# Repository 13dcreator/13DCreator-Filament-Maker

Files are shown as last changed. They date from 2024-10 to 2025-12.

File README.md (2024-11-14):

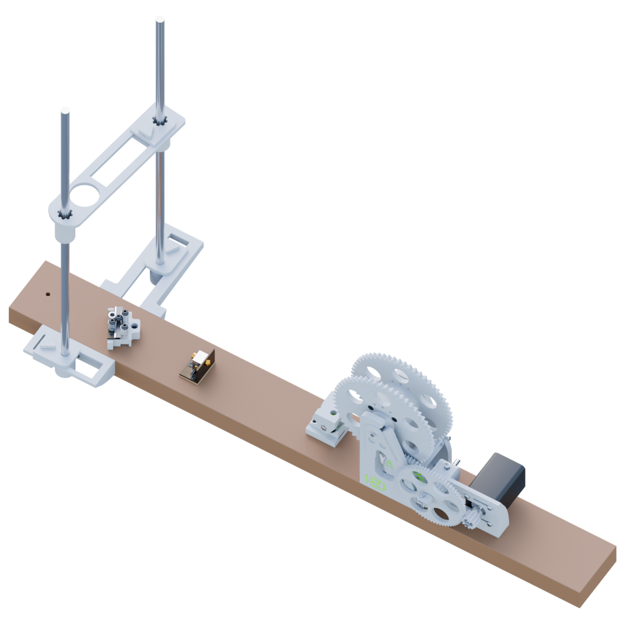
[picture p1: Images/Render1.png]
Render1


[English](#english)

## Bahasa Indonesia

PET Filament Maker adalah perangkat yang dirancang untuk mengubah botol PET bekas menjadi filament 3D yang dapat digunakan kembali. Proyek ini bertujuan memberikan solusi yang ramah lingkungan, mengurangi limbah plastik sekaligus menghemat biaya material filament yang biasanya harus dibeli.

Rekomendasi Penggunaan Extruder:
Disarankan untuk menggunakan Dual Gear Extruder agar cengkeraman terhadap filament lebih kuat dan stabil, karena diameter filament mungkin tidak selalu konsisten.

Proses Kerja:
1. Persiapan Bahan: Botol PET bekas dibersihkan terlebih dahulu untuk menghilangkan label dan kotoran agar siap diproses.
2. Pelurusan Permukaan Botol: Botol PET yang memiliki permukaan tidak rata perlu diluruskan dengan memanaskan permukaannya sambil memutar botol menggunakan blower, heatgun atau di atas kompor. Proses pemanasan ini mengurangi lekukan, memungkinkan permukaan botol menjadi lebih rata dan mudah dipotong.
3. Ekstrusi: Botol PET dipotong menjadi strip dan dipanaskan hingga lunak untuk diubah menjadi bentuk filament, kemudian ditarik secara otomatis agar ukuran filament konsisten.
4. Pemeriksaan Kualitas Filament: Filament yang dihasilkan diperiksa untuk memastikan kualitas dan ketebalan sesuai spesifikasi.

Kelemahan:
1. Hasil filament yang dihasilkan tidak selalu konsisten, sangat tergantung dengan konsistensi potongan.
2. Dapat mengakibatkan macet jika diameter filament terlalu kecil atau terlalu besar.
3. Putaran stepper motor sering terhambat saat ESP8266 terhubung ke WiFi. Pastikan untuk memutus koneksi WiFi pada ESP8266 saat proses pembuatan filament.
4. Suara stepper motor cukup berisik; coba atur microstepping untuk menguranginya.
5. Suara cutter cukup keras saat memotong botol, terutama untuk botol PET yang tebal; bisa disiasati dengan menggunakan pelumas.
6. Deteksi filament terkadang terhenti jika filament yang ditarik oleh filament puller kendur atau terlalu tipis.

Kesimpulan:

Filament Maker dari botol PET bekas ini memberikan solusi ekonomis sekaligus ramah lingkungan, memungkinkan pengguna mendaur ulang plastik bekas menjadi filament yang siap digunakan dalam pencetakan 3D. Dengan desain yang mudah dioperasikan, kontrol otomatis yang presisi, dan sistem modular yang mempermudah perawatan, proyek ini menawarkan pendekatan baru yang berkelanjutan dalam produksi material 3D.

## English

PET Filament Maker is a tool designed to convert used PET bottles into reusable 3D filament. This project aims to provide an eco-friendly solution by reducing plastic waste while saving on filament material costs, which are typically purchased.

Extruder Usage Recommendation: It is recommended to use a Dual Gear Extruder for stronger and more stable grip on the filament, as the filament diameter may not always be consistent.

How It Works:

1. Material Preparation: The used PET bottles are cleaned first to remove labels and dirt, making them ready for processing.
2. Surface Straightening: PET bottles with uneven surfaces need to be straightened by heating the surface while rotating the bottle using a blower, heat gun, or stovetop. This heating process reduces the wrinkles, making the bottle surface smoother and easier to cut.
3. Extrusion: The PET bottles are cut into strips and heated until soft to be shaped into filament, then automatically drawn to ensure the filament size remains consistent.
4. Filament Quality Check: The produced filament is checked to ensure that its quality and thickness meet the specifications.

Disadvantages:

1. The filament produced is not always consistent and highly depends on the consistency of the cuts.
2. It may cause clogging if the filament diameter is too small or too large.
3. The stepper motor's rotation is often hindered when the ESP8266 is connected to WiFi. Be sure to disconnect the WiFi on the ESP8266 during the filament-making process.
4. The stepper motor can be quite noisy; try adjusting the microstepping to reduce the noise.
5. The cutter can be loud when cutting bottles, especially for thick PET bottles; this can be mitigated by using lubricants.
6. Filament detection may sometimes stop if the filament pulled by the filament puller is slack or too thin.

Conclusion:

This PET Bottle Filament Maker provides an economical and eco-friendly solution, allowing users to recycle used plastic into filament ready for 3D printing. With an easy-to-operate design, precise automatic control, and a modular system that simplifies maintenance, this project offers a sustainable approach to 3D material production.

## Download Documentation in PDF Format for Easier Viewing by:

Open the documentation file > File > Download > PDF Document (.pdf)

[Dokumentasi Bahasa Indonesia](https://docs.google.com/document/d/12gZyxp6K4KovrQUbeszD_oszRoTwFk6smVtTxPSdtus/edit?usp=sharing)

[English Documentation](https://docs.google.com/document/d/1ymJz-RaAGOkLNr1P1AoNhB6fQcQ51tFpCmrfthYmQNY/edit?usp=sharing)

[BOM/Bahan yang Diperlukan](https://docs.google.com/spreadsheets/d/1hQpWlGkNJCp8BHFFs-p2dSdpw58OgJwYKI5ZXl5ccxk/edit?usp=sharing)

## 3D Print Results

<table>
  <tr>
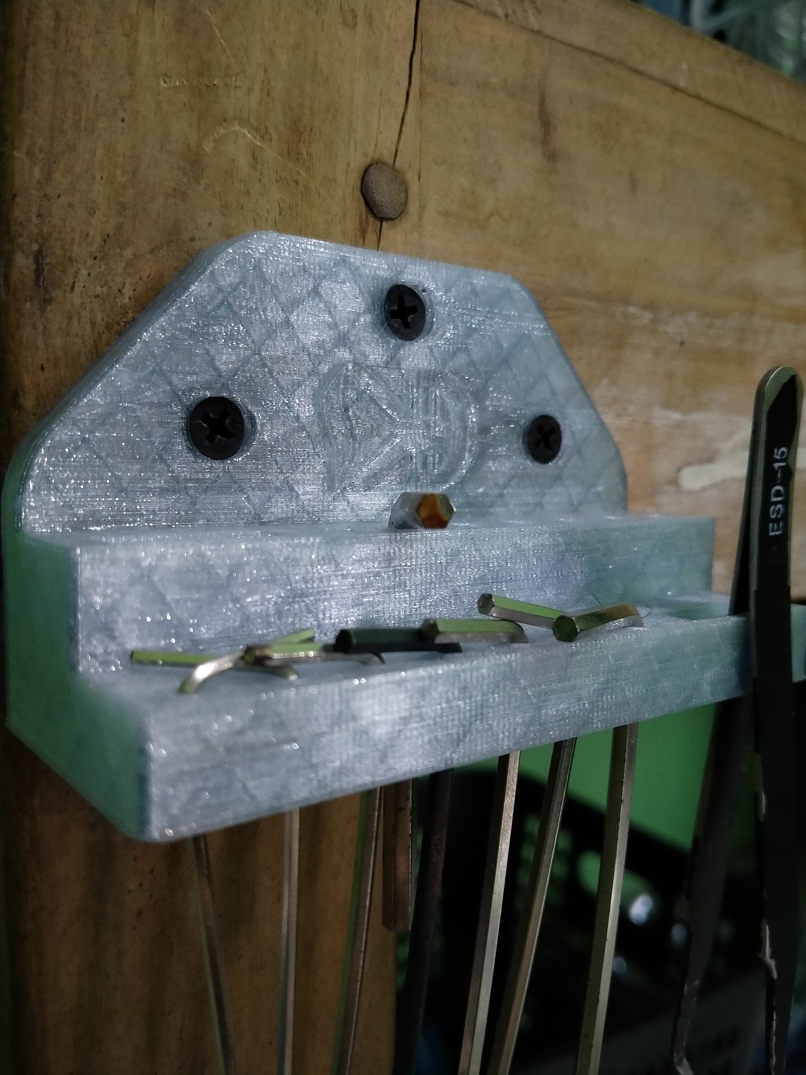
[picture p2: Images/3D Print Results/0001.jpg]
    <td></td>
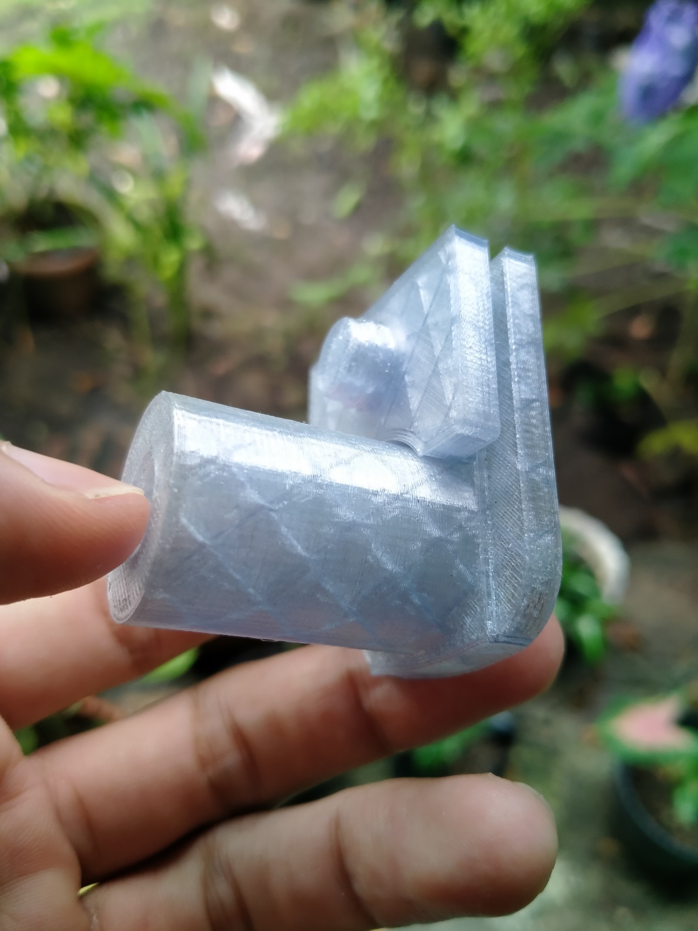
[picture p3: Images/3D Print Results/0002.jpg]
    <td></td>
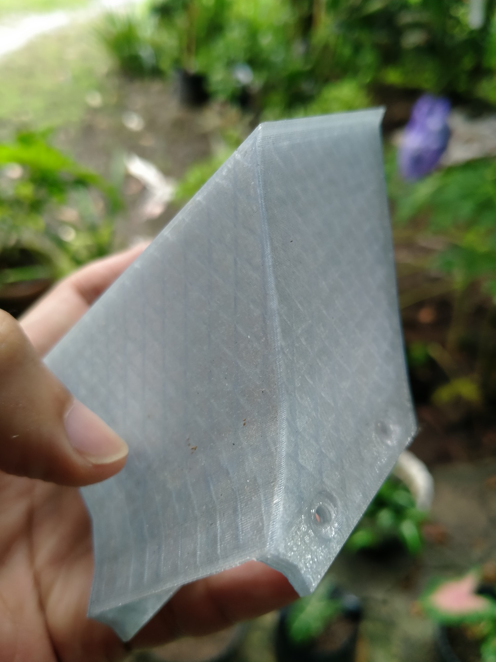
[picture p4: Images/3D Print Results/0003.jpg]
    <td></td>
  </tr>
  <tr>
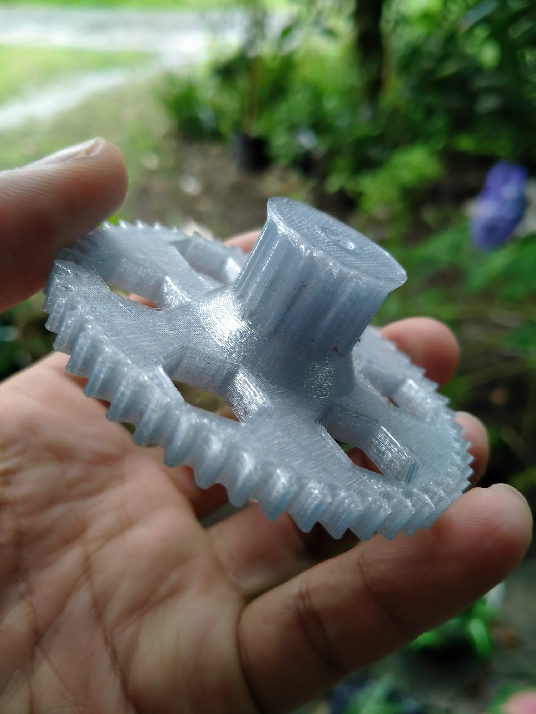
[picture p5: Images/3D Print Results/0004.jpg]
    <td></td>
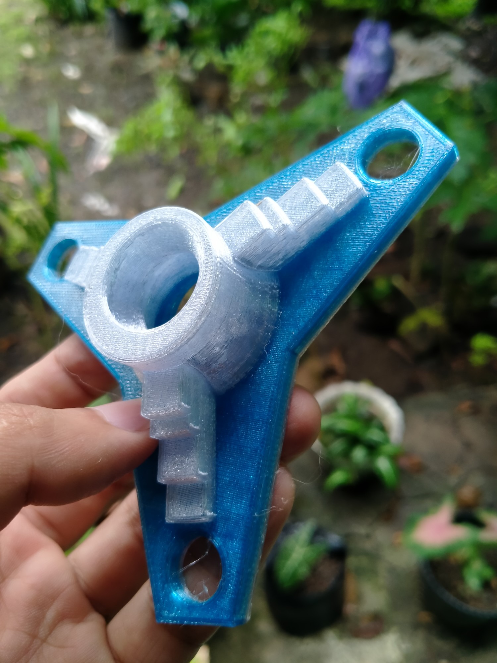
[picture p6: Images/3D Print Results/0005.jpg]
    <td></td>
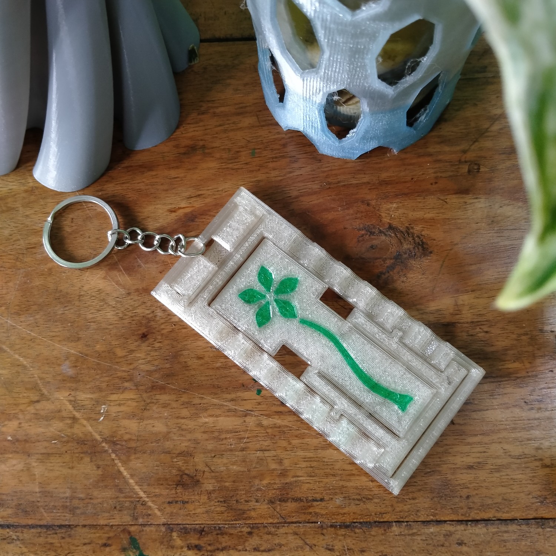
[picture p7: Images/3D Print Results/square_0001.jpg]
    <td></td>
  </tr>
  <tr>
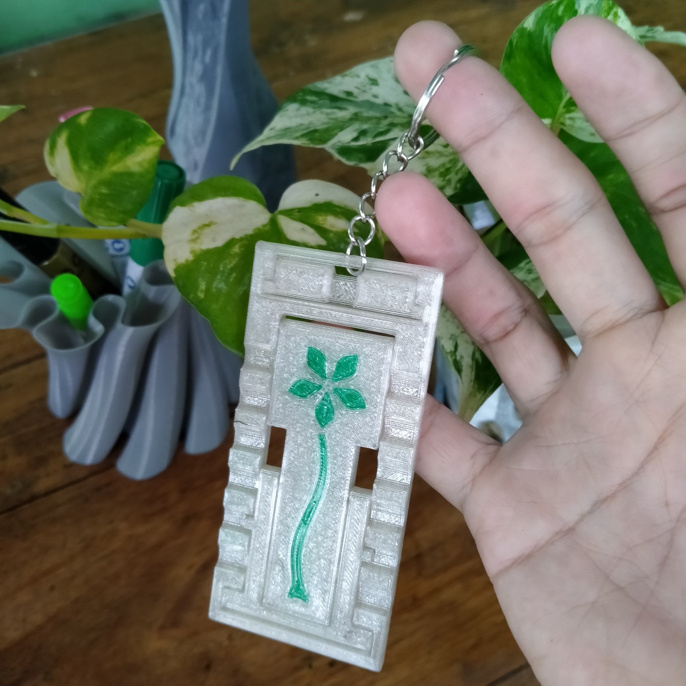
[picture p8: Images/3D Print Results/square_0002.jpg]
    <td></td>
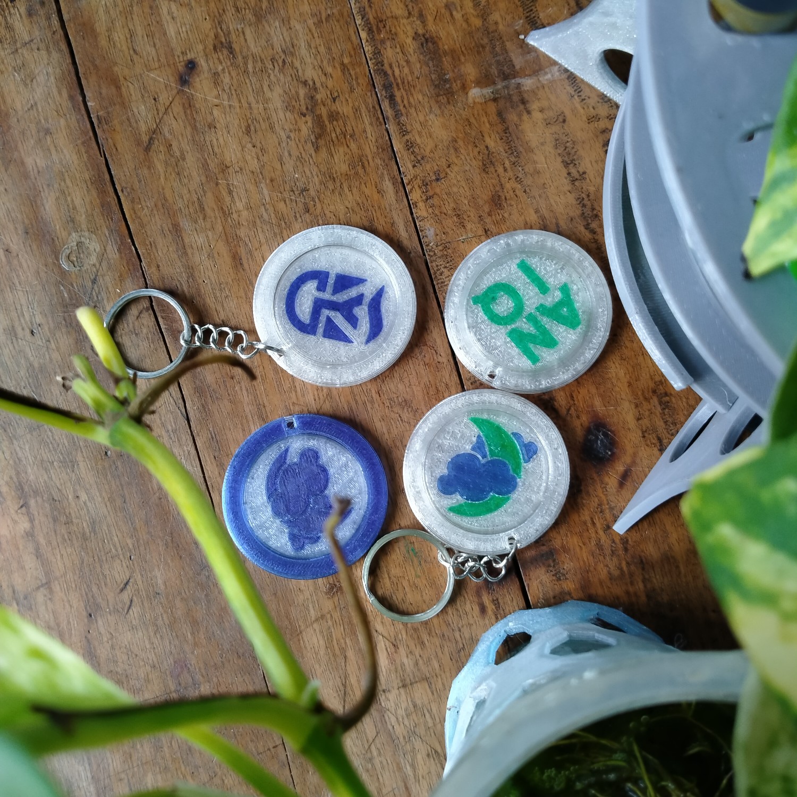
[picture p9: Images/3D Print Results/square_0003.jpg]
    <td></td>
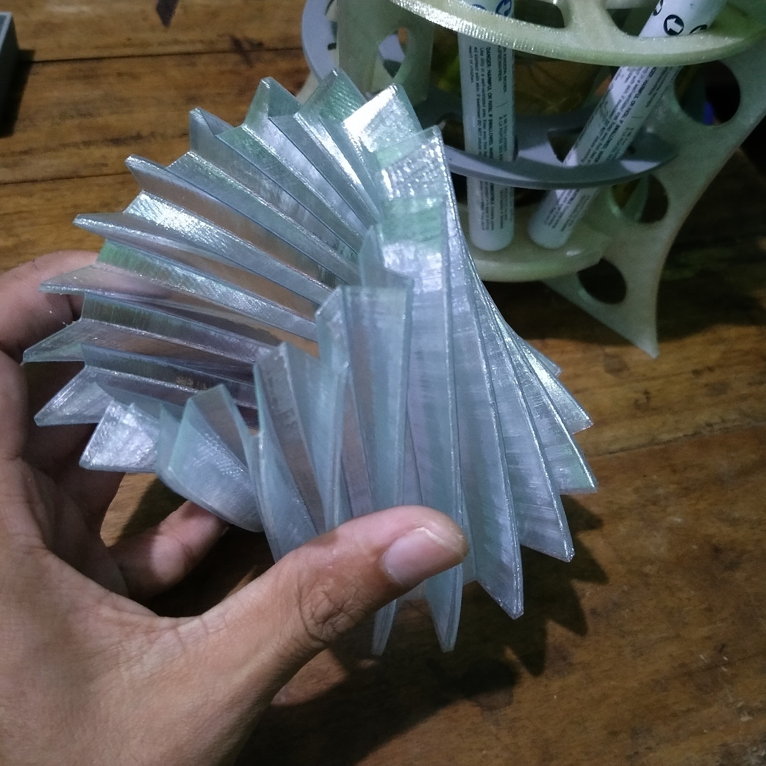
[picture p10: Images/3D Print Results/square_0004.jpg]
    <td></td>
  </tr>
</table>

## Filament Maker

<table>
  <tr>
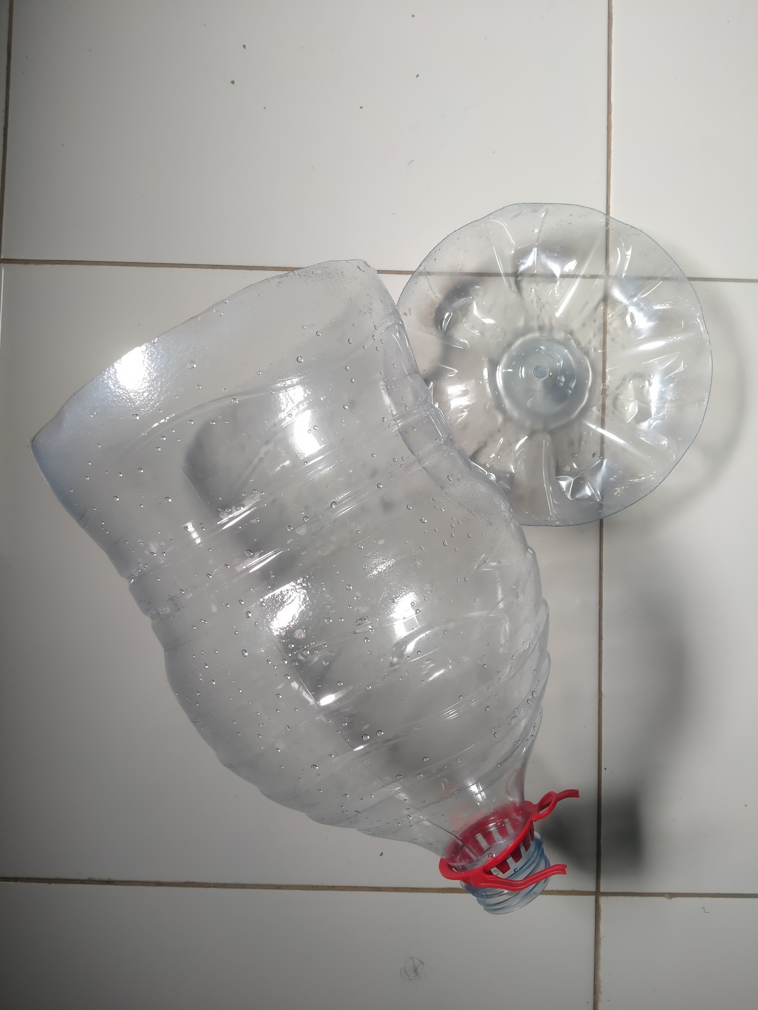
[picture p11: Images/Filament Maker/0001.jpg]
    <td></td>
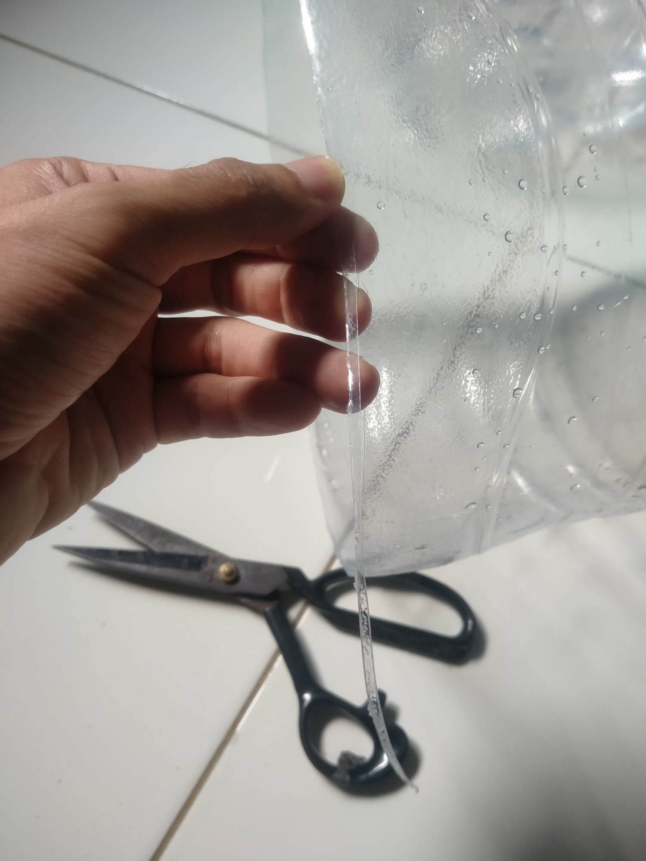
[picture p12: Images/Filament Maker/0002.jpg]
    <td></td>
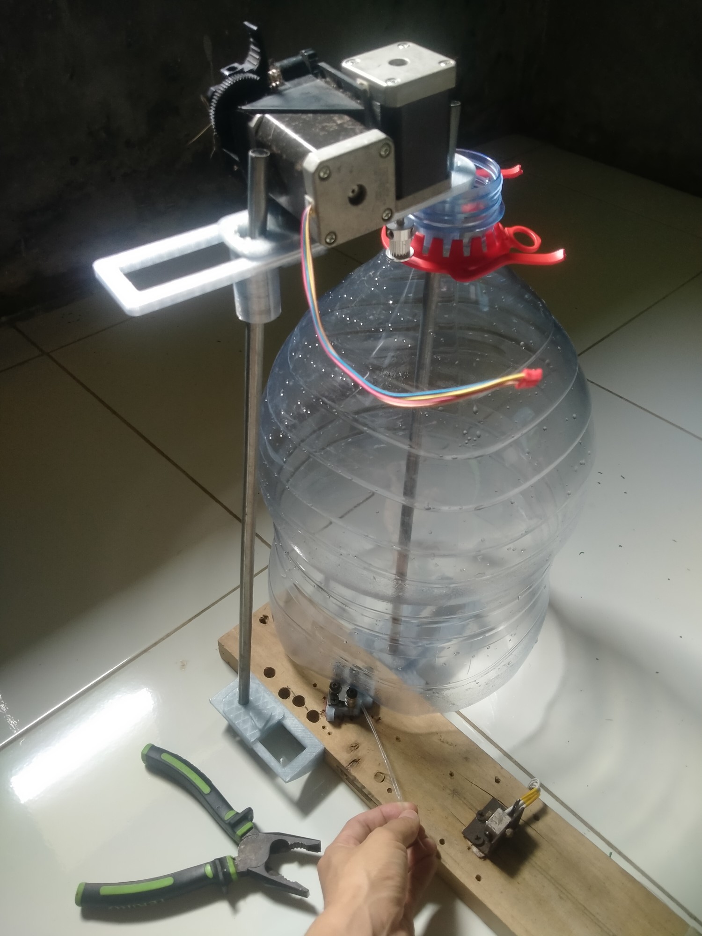
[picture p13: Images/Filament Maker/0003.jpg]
    <td></td>
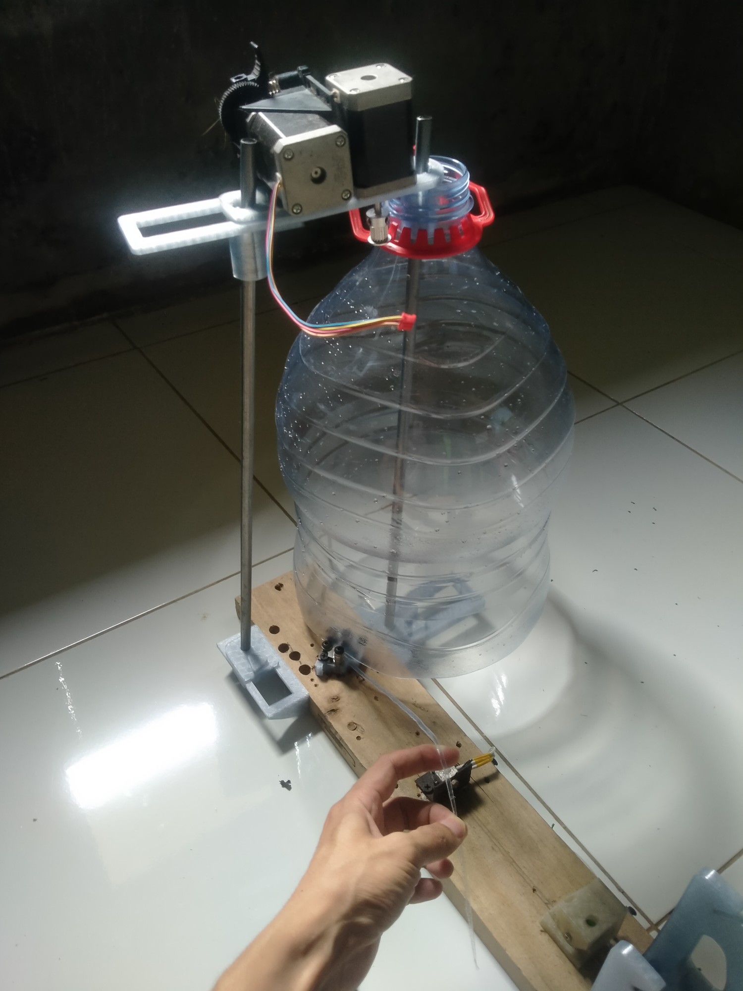
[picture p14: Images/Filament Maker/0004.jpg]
    <td></td>
  </tr>
  <tr>
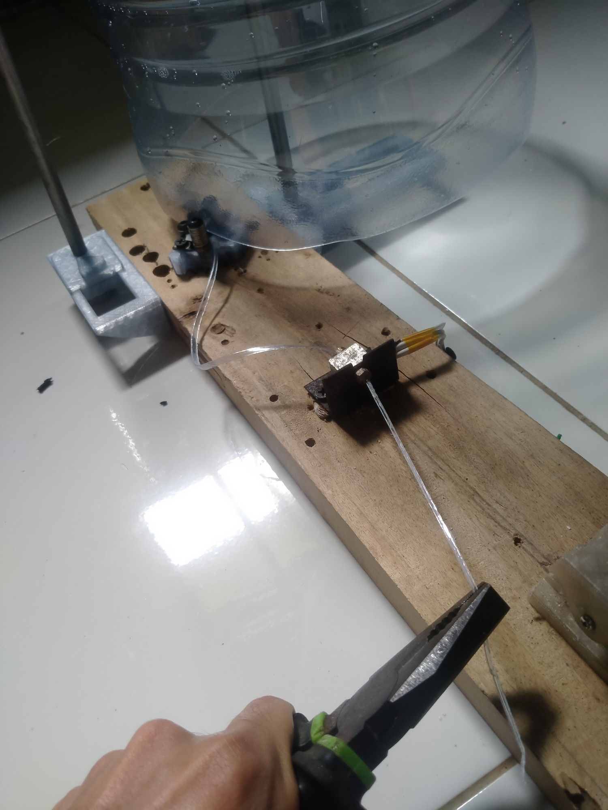
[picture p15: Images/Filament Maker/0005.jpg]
    <td></td>
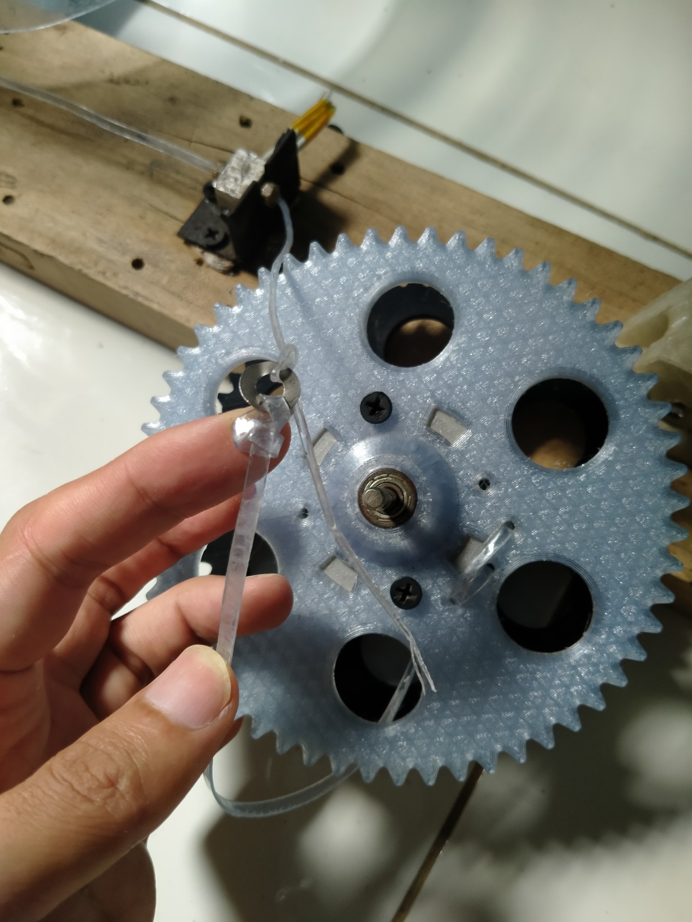
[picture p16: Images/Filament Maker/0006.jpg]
    <td></td>
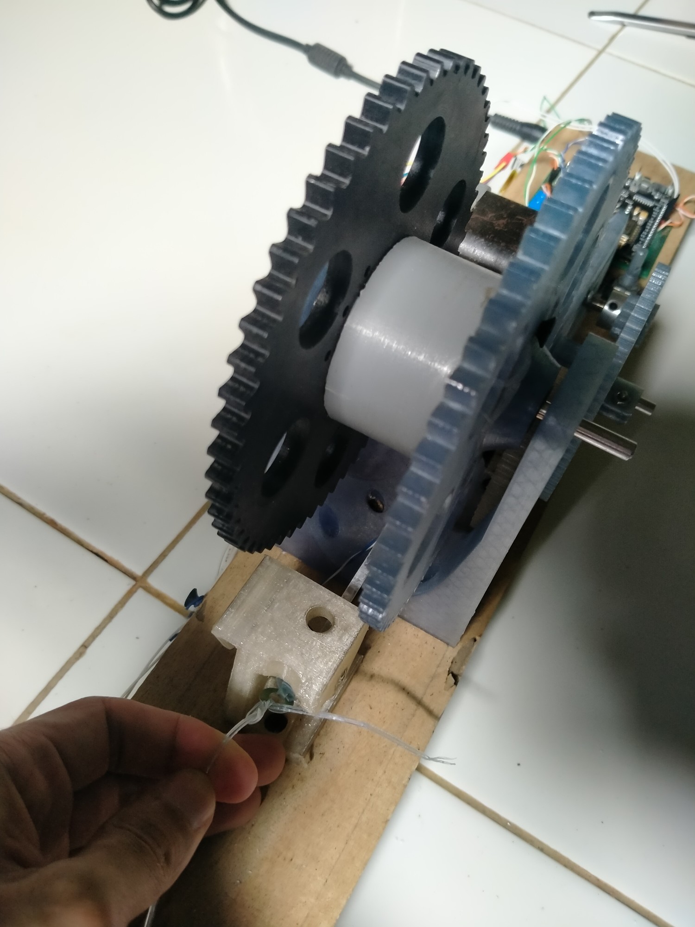
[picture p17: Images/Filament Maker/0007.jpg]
    <td></td>
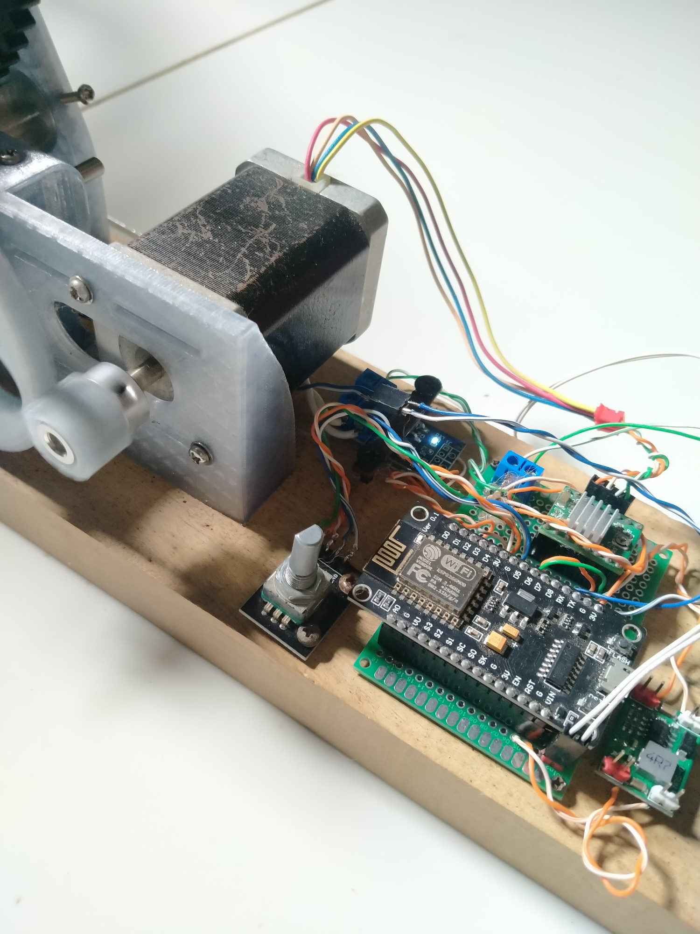
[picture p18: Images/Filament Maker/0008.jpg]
    <td></td>
  </tr>
  <tr>
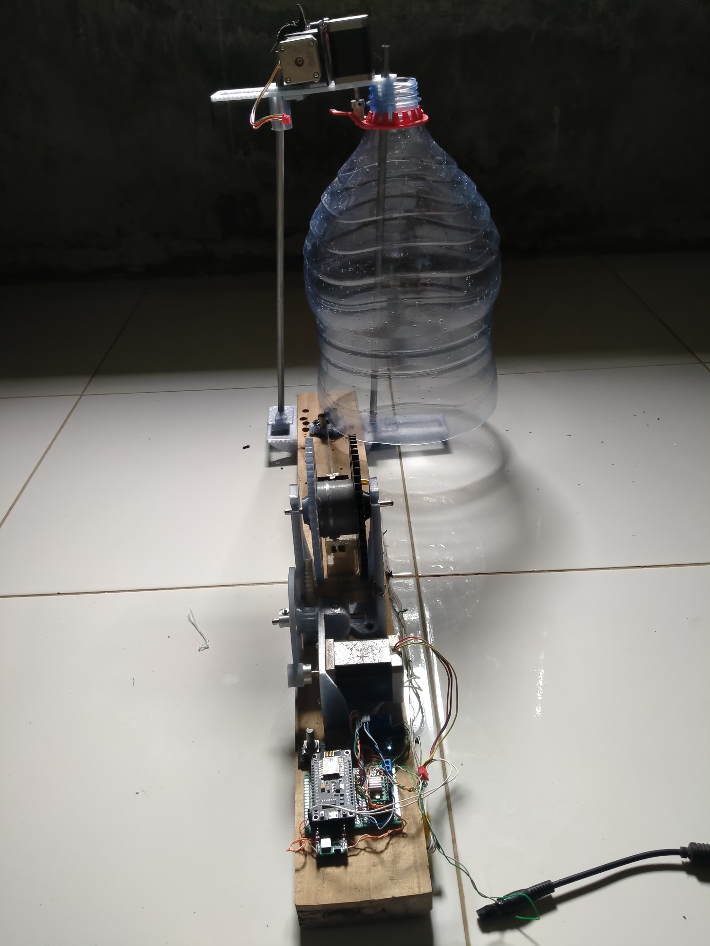
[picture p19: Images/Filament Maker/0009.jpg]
    <td></td>
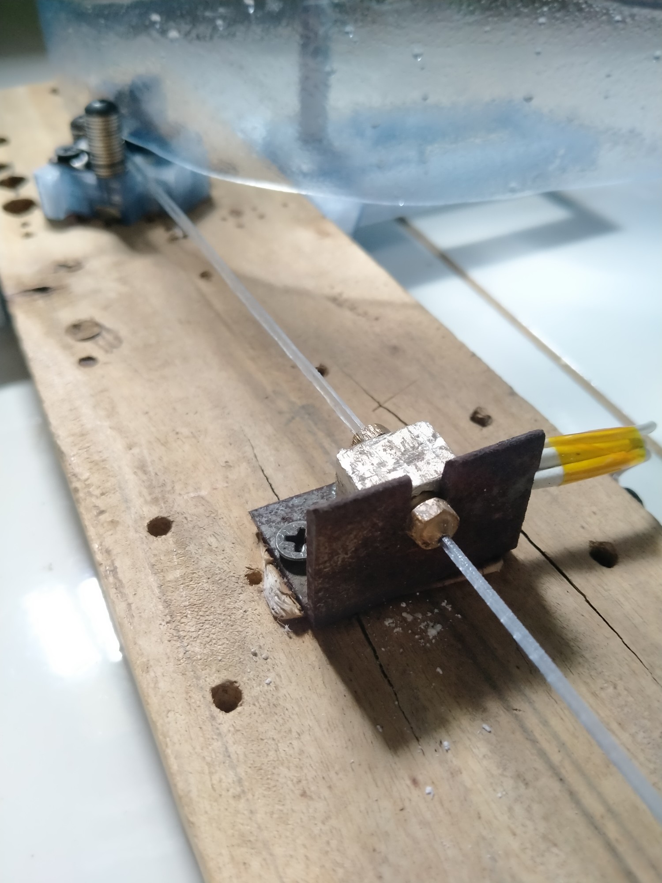
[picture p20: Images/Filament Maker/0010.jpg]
    <td></td>
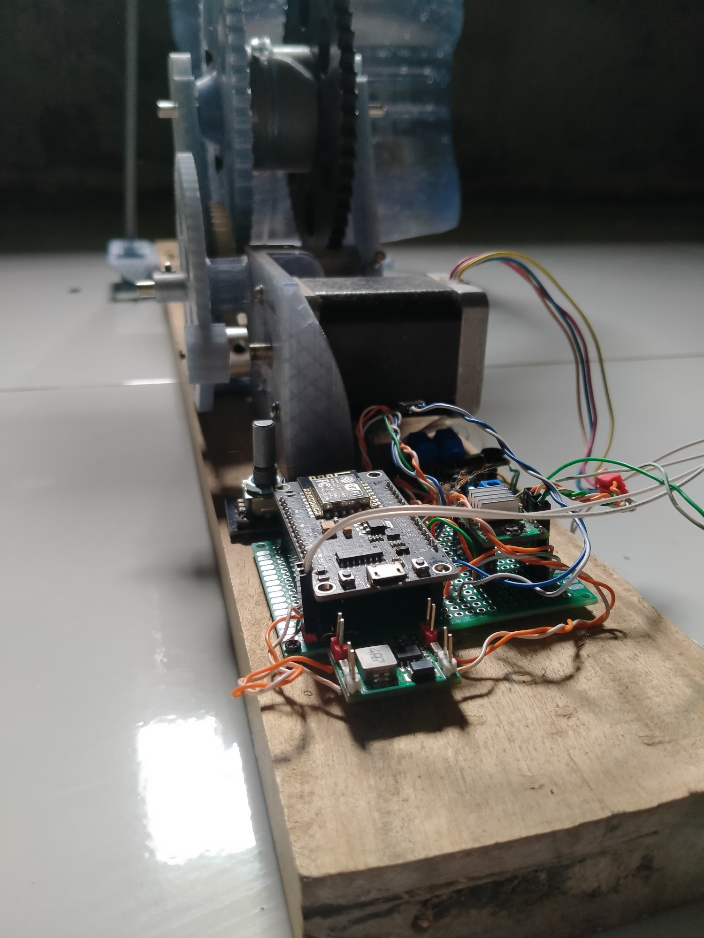
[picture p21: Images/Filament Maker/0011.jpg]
    <td></td>
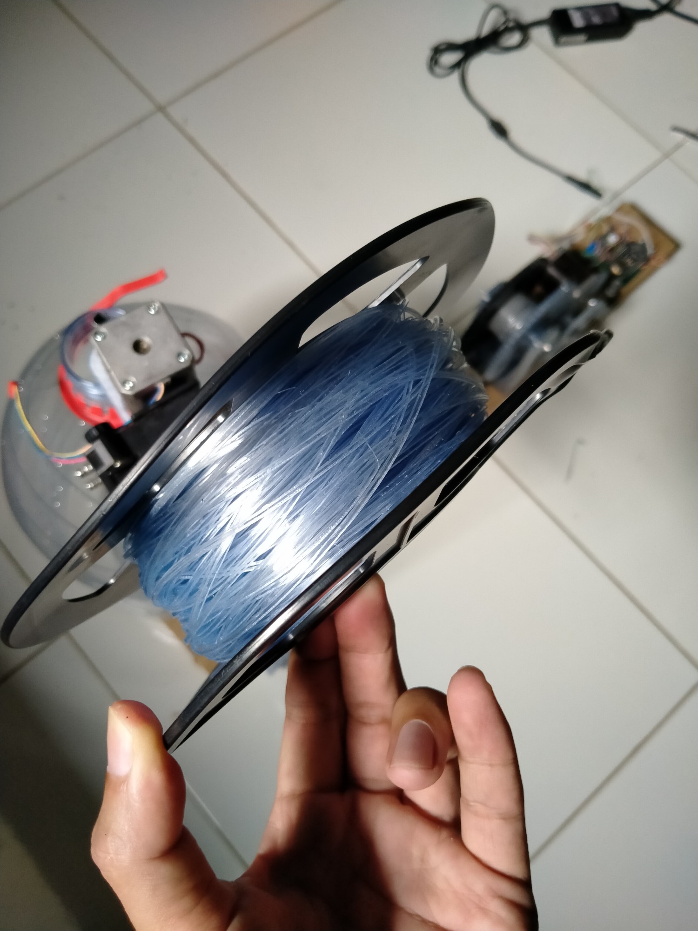
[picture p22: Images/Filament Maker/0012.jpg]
    <td></td>
  </tr>
  <tr>
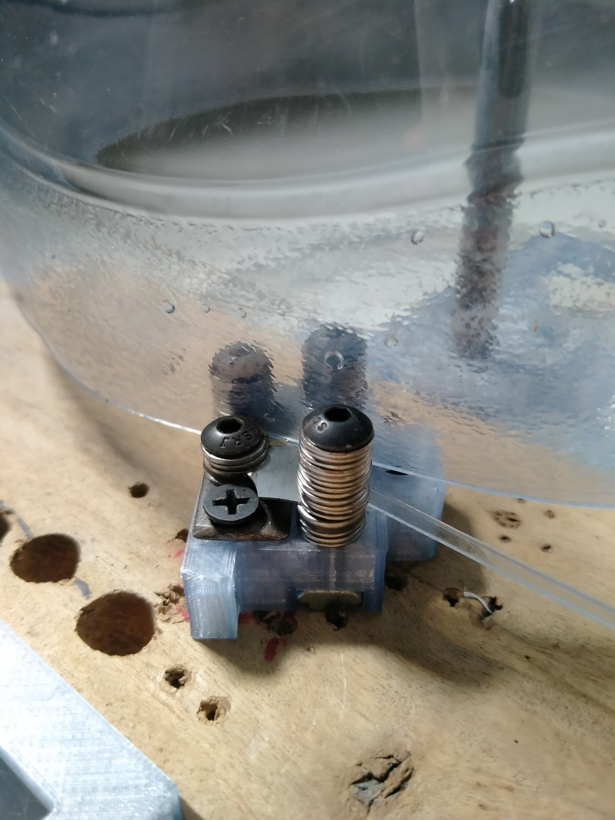
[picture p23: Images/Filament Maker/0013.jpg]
    <td></td>
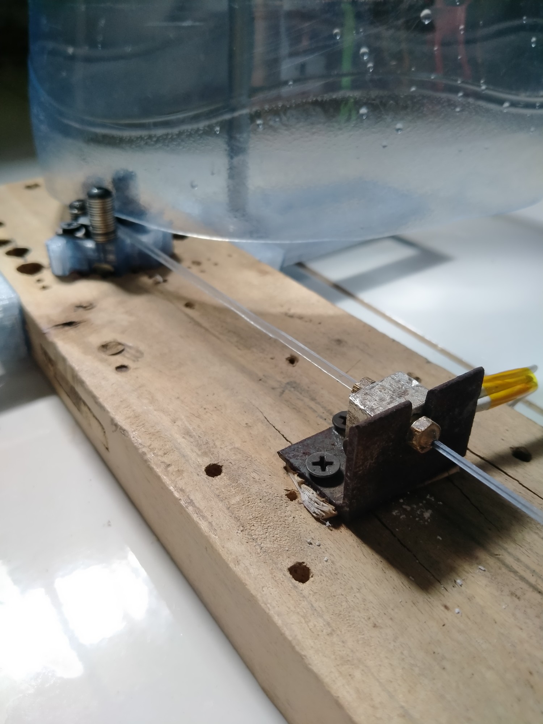
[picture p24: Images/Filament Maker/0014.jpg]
    <td></td>
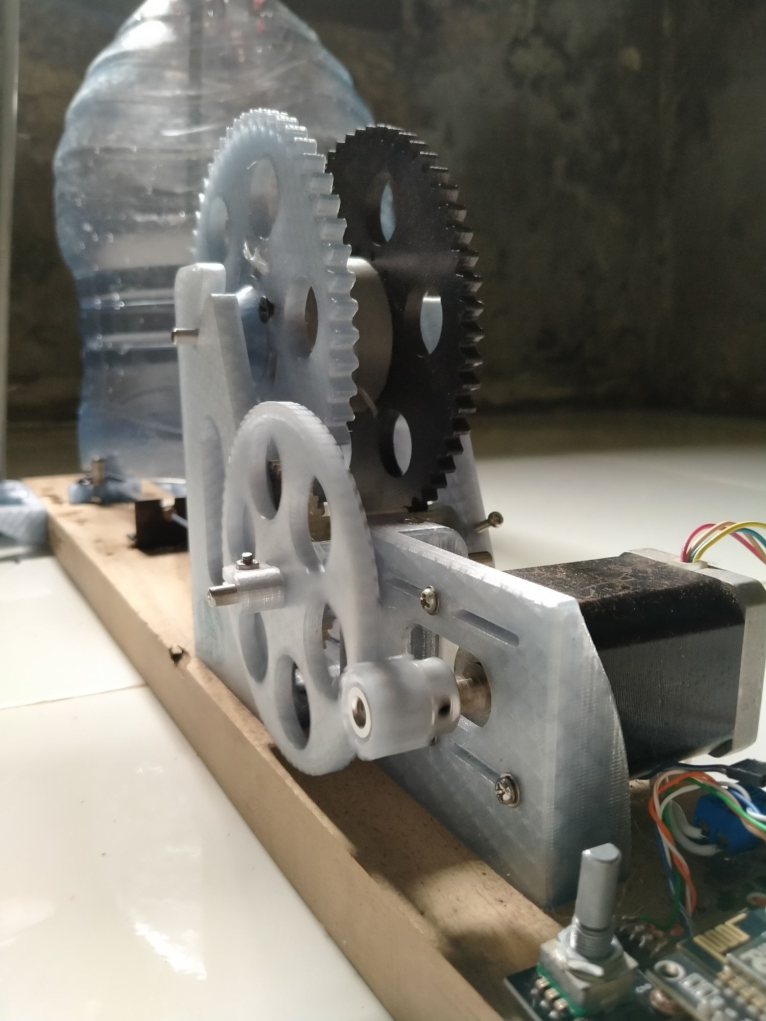
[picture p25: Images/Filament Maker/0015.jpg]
    <td></td>
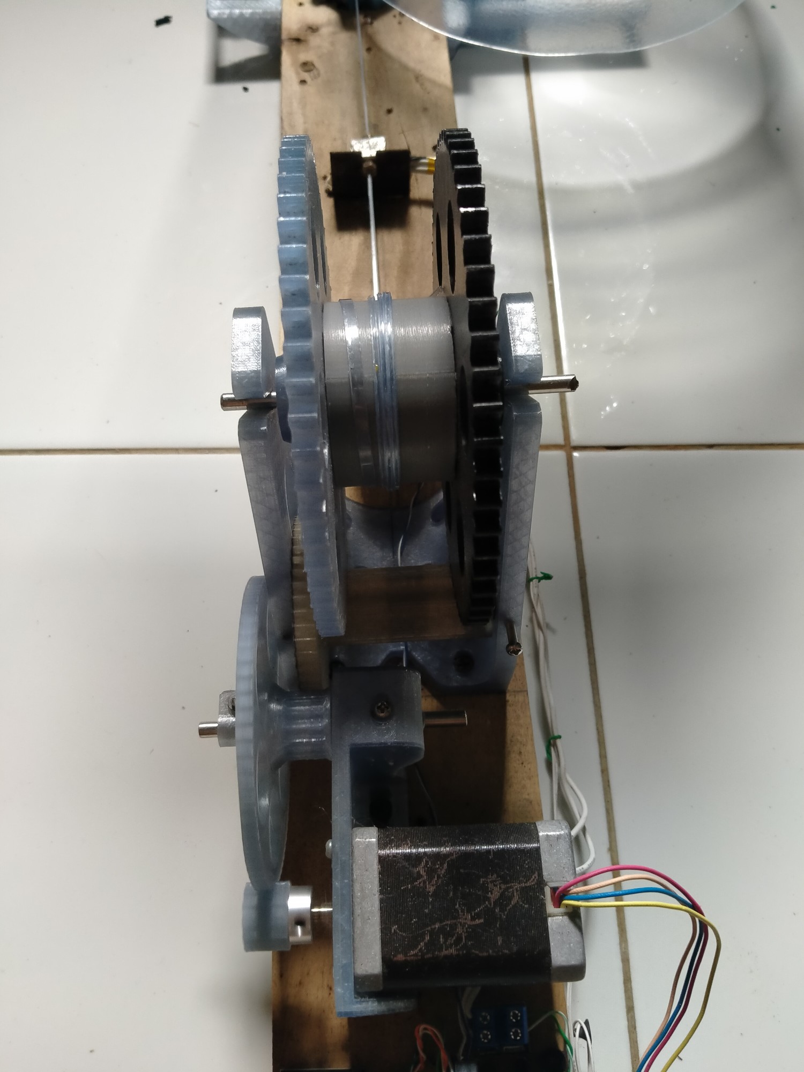
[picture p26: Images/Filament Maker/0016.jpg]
    <td></td>
  </tr>
</table>

## Appreciation

You can show your appreciation for this project through the following link:

<a href="https://www.paypal.com/paypalme/alif2113">
    
</a>
&nbsp;
<a href="https://saweria.co/13dcreator">
    
</a>

<br>
Thank you for your appreciation!

## Connect with Us

<p align="left">
    
  
</p>

## Contact Me



## License

Please refer to the LICENSE file.

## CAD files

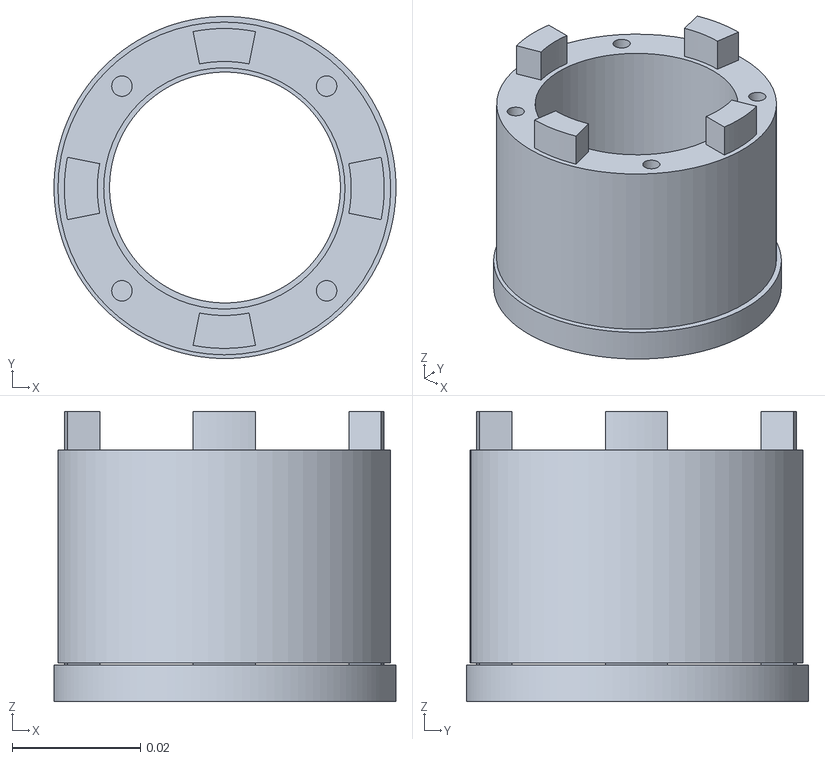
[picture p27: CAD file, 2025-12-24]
Stl/Filament Puller/Main Gear (Roll) V3 M3 Holes Less Suport.stl
0.0533 x 0.0533 x 0.0452

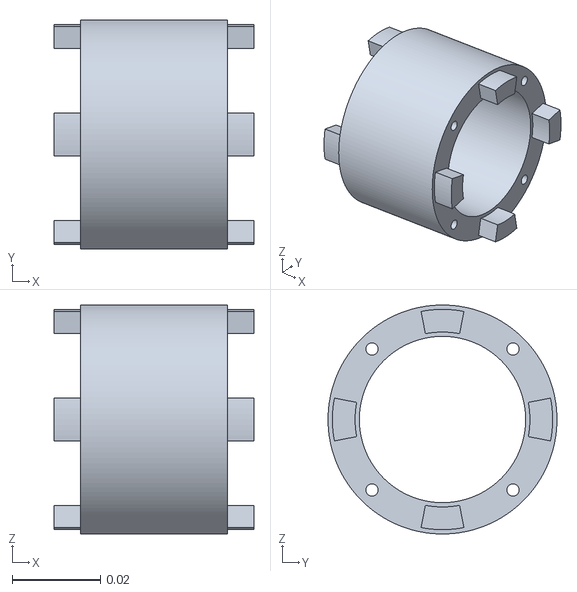
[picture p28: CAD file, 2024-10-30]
Stl/Filament Puller/Main Gear (Roll).stl
0.0452 x 0.0518 x 0.0518

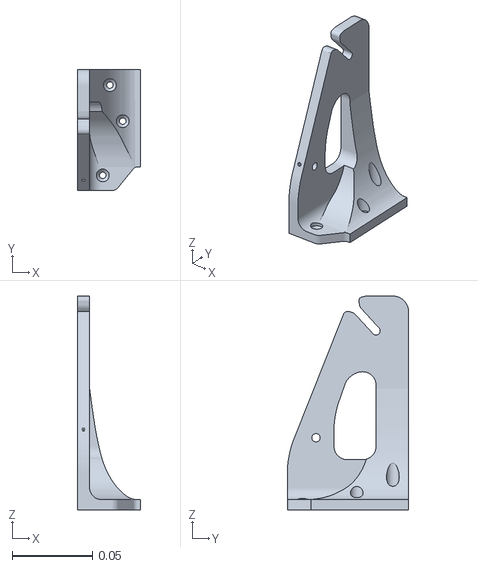
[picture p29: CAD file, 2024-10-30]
Stl/Filament Puller/Main Gear Mount_V2 Left.stl
0.0393 x 0.0758 x 0.134

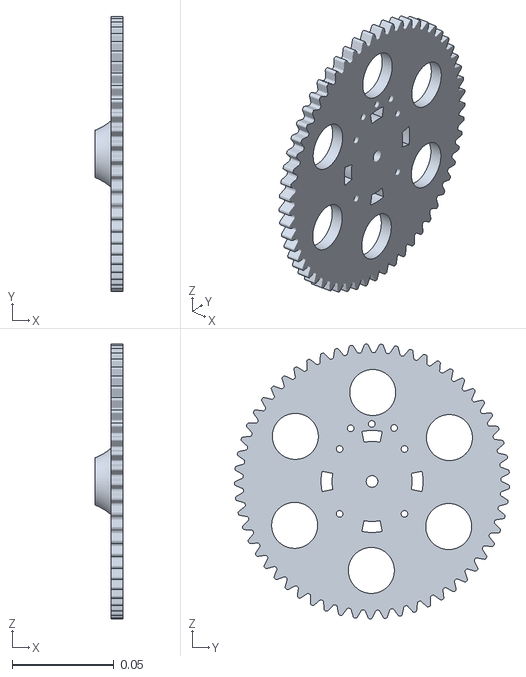
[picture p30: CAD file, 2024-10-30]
Stl/Filament Puller/Main Gear V2 Left.stl
0.014 x 0.135 x 0.135

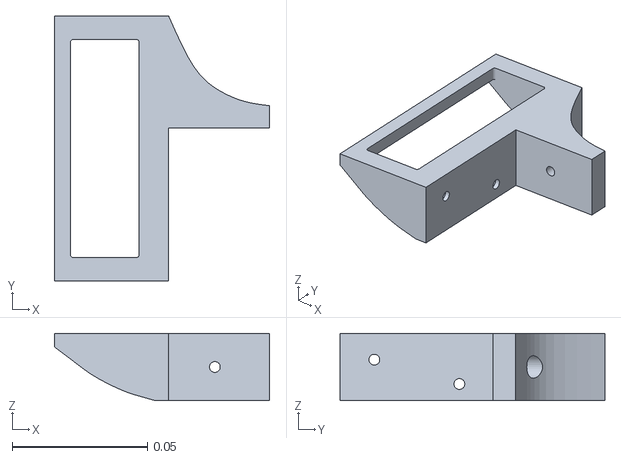
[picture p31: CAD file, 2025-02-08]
Stl/Bottom Counterweight/Handle2 Suport V2.stl
0.0796 x 0.0981 x 0.0249

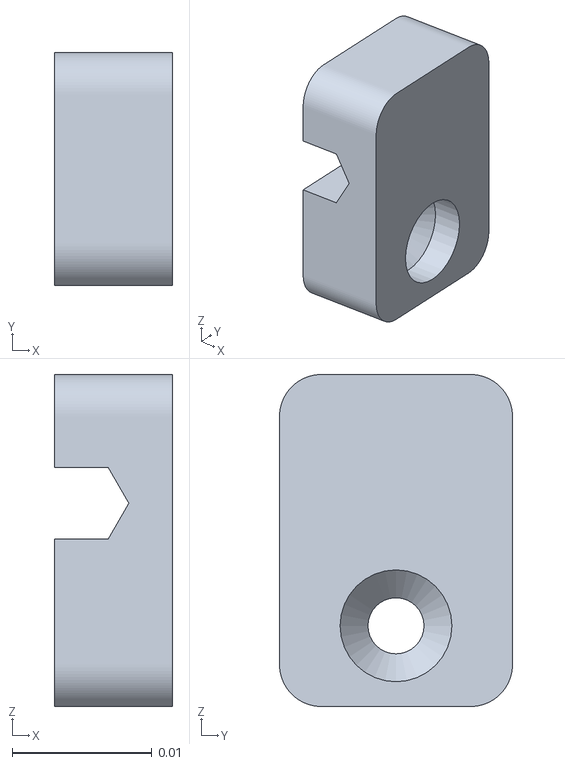
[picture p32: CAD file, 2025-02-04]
Stl/Cable Clamp/Cable Clamp.stl
0.00844 x 0.0167 x 0.0237

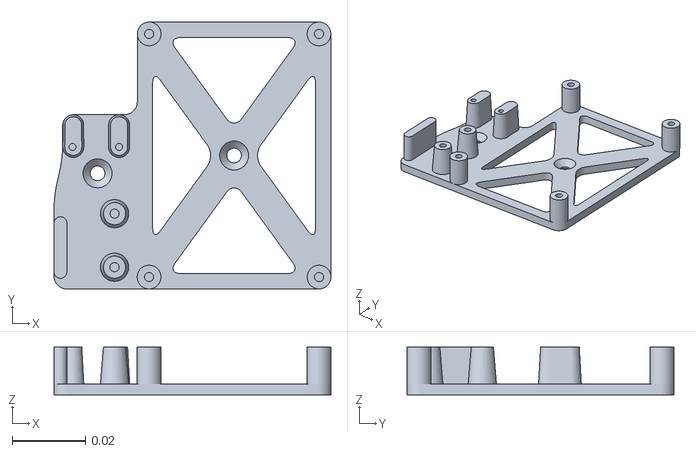
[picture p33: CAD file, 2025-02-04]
Stl/Case ESP8266/Board Case No Thread Encoder.stl
0.0755 x 0.0728 x 0.013

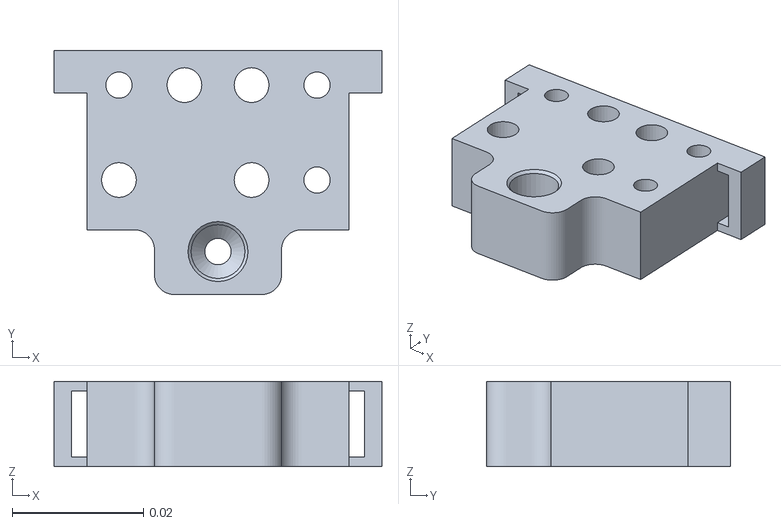
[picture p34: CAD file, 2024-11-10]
Stl/Cutter/BaseV3 Bottle Cutter Spacer.stl
0.05 x 0.0372 x 0.013

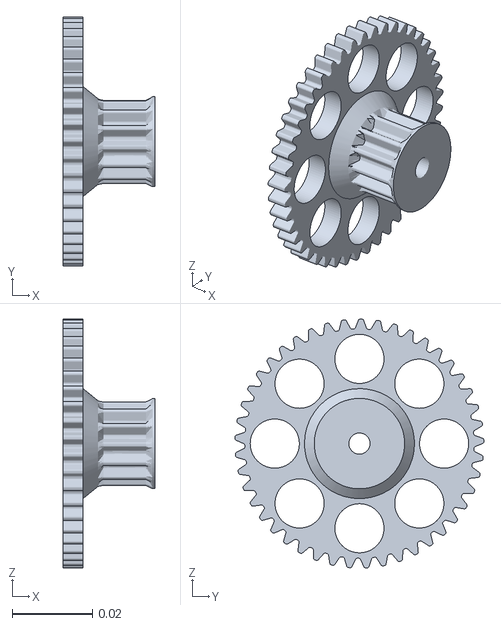
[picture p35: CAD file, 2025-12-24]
Stl/Dynamo WIK25GAD027/Primary Gear2 Smaller.stl
0.0229 x 0.0619 x 0.0619

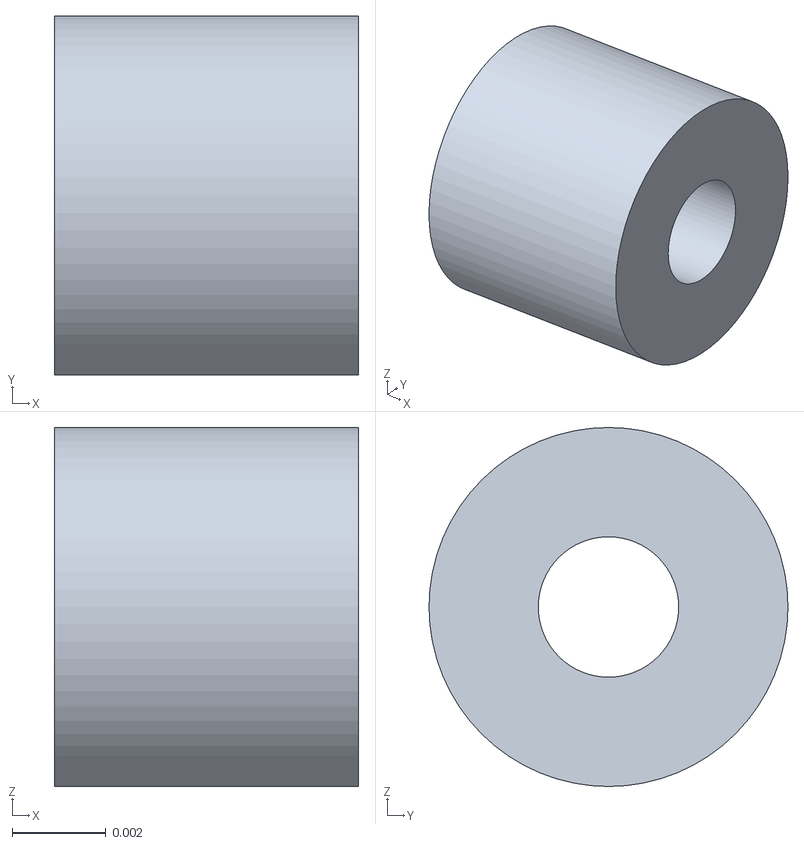
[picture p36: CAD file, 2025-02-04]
Stl/Filament Straightener/Filament Straightener Spacer V2.stl
0.0065 x 0.00767 x 0.00767

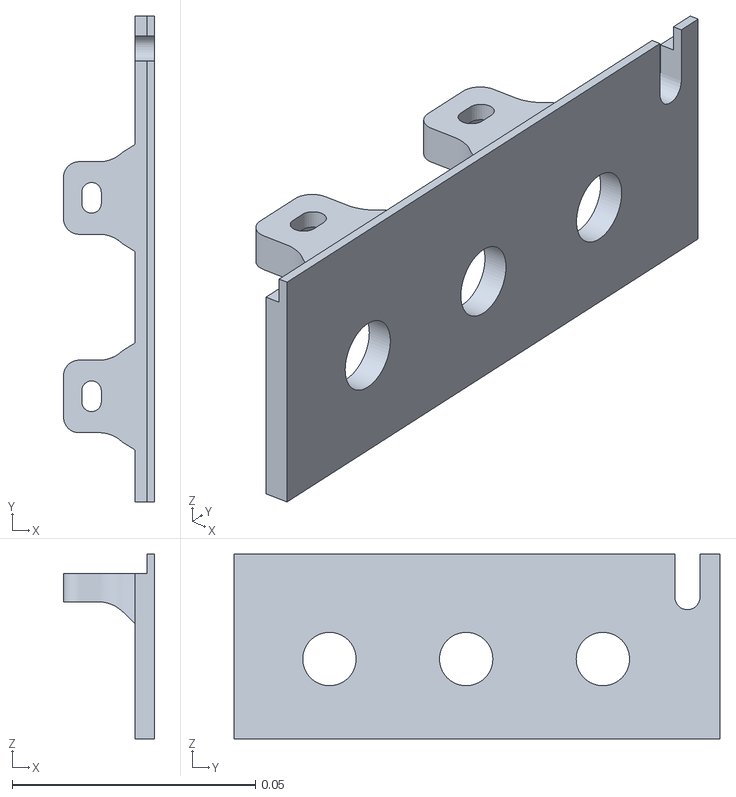
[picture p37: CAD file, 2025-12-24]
Stl/Panel/Panel Rear.stl
0.0187 x 0.1 x 0.038

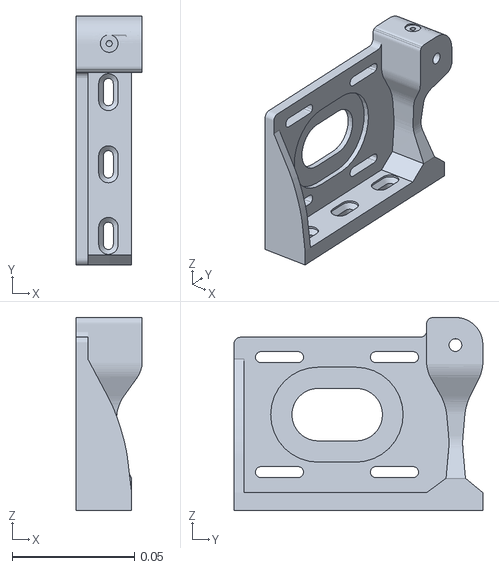
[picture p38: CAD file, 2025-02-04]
Stl/Stepper Motor Component/Housing N23 V2.stl
0.0271 x 0.102 x 0.0789

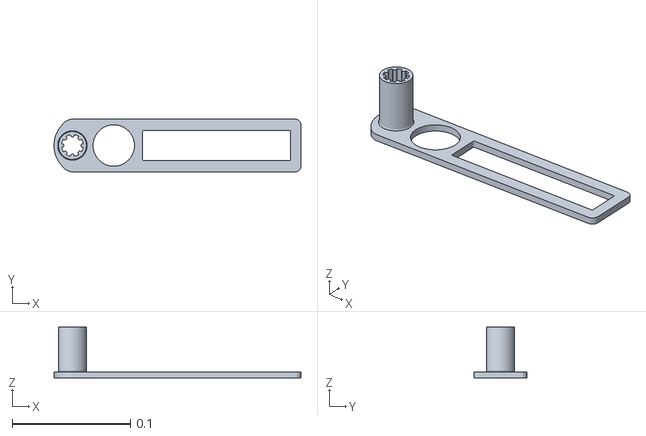
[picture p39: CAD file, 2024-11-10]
Stl/Top Counterweight/Top Handle.stl
0.209 x 0.0447 x 0.0429

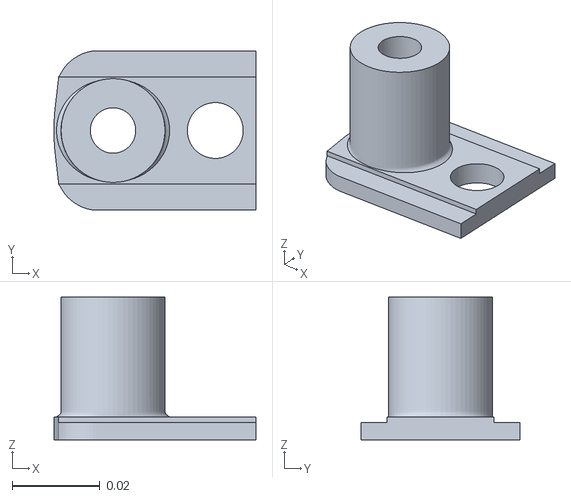
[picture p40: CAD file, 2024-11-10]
Stl/Bottom Counterweight/Shaft Hole Suport.stl
0.0459 x 0.0363 x 0.0325

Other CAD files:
Stl/Filament Puller/Main Gear Mount_V2 Right.stl
Stl/Filament Puller/Main Gear V2 Right.stl
Stl/Cable Clamp/Corner Cable Clamp.stl
Stl/Case ESP8266/Board Case.stl
Stl/Bottom Counterweight/Handle1 Suport.stl
Stl/Bottom Counterweight/Handle2 Suport.stl
Stl/Bottom Counterweight/Nut.stl
Stl/Bottom Counterweight/Screw.stl
Stl/Cutter/BaseV2 Bottle Cutter Spacer.stl
Stl/Cutter/Guide Bottle Cutter Spacer.stl
Stl/Cutter/Spacer.stl
Stl/Dynamo WIK25GAD027/Housing WIK25GAD027.stl
Stl/Dynamo WIK25GAD027/Primary Gear2.stl
Stl/Dynamo WIK25GAD027/WIK25GAD027 Gear.stl
Stl/Filament Puller/Filament Puller Lock1 V2.stl
Stl/Filament Puller/Filament Puller Lock1.stl
Stl/Filament Puller/Filament Puller Lock2 V2.stl
Stl/Filament Puller/Filament Puller Lock2.stl
Stl/Filament Puller/Secondary Gear.stl
Stl/Filament Straightener/Filament Straight Bearing.stl
Stl/Filament Straightener/Filament Straight.stl
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

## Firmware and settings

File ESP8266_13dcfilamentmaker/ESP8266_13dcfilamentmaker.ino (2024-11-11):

// Some libraries used in this project may be licensed under different licenses. 
// Please refer to the LICENSE file for more information about those libraries.

#include <ESP8266WiFi.h>          // Library for managing WiFi functionality on the ESP8266
#include <ESPAsyncWebServer.h>     // Library for asynchronous web server on ESP8266
#include <ESPAsyncTCP.h>           // Library for asynchronous TCP communication
#include <Encoder.h>               // Library to interface with rotary encoders
#include <AccelStepper.h>          // Library for controlling stepper motors
#include <PID_v1.h>                // Library for PID control algorithm
#include <FS.h>                    // Library for SPIFFS (SPI Flash File System)
#include <Ticker.h>                // Library for Ticker, used for timed callbacks


/*
 * The code below is licensed under the MIT License.
 * 
 * MIT License
 * 
 * Copyright (c) 2024 13DCreator
 * 
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
 * THE SOFTWARE IS PROVIDED "AS IS", WITHOUT WARRANTY OF ANY KIND, EXPRESS OR
 * IMPLIED, INCLUDING BUT NOT LIMITED TO THE WARRANTIES OF MERCHANTABILITY,
 * FITNESS FOR A PARTICULAR PURPOSE, AND NONINFRINGEMENT. IN NO EVENT SHALL THE
 * AUTHORS OR COPYRIGHT HOLDERS BE LIABLE FOR ANY CLAIM, DAMAGES, OR OTHER
 * LIABILITY, WHETHER IN AN ACTION OF CONTRACT, TORT OR OTHERWISE, ARISING FROM,
 * OUT OF OR IN CONNECTION WITH THE SOFTWARE OR THE USE OR OTHER DEALINGS IN THE
 * SOFTWARE.
 */
 
// Define pins for connecting components
#define CLK_PIN D2
#define DT_PIN D3
#define BUTTON_PIN D4
#define SWITCH_PIN D8
#define STEP_PIN D6
#define DIR_PIN D7
#define ENABLE_PIN D5
#define MOSFET_PIN D1
 
 
// Thermistor parameters

      // Uncomment if using a 10k resistor
const float R1 = 10000; // Pull-up resistor value in ohms, used with the thermistor
      // Uncomment if using a 100k resistor
//const float R1 = 100000; // Pull-up resistor value in ohms, used with the thermistor

const float BETA = 3950; // Beta coefficient of the thermistor for temperature calculations
const float T0 = 298.15; // Reference temperature in Kelvin (25°C)
const float R0 = 100000; // Thermistor resistance at reference temperature (in ohms)

// WiFi credentials for AP mode
const char* apSSID = "13DC";
const char* apPassword = "13dcreator";

// Interval for temperature reading
const int temperatureUpdateInterval = 3000; // 3 seconds

Encoder encoder(CLK_PIN, DT_PIN);
AsyncWebSocket webSocket("/ws");
AsyncWebServer server(80);
AccelStepper stepper(AccelStepper::DRIVER, STEP_PIN, DIR_PIN);

// PID variables
double Setpoint = 175.0, Input, Output; // Set temperature
double Kp = 11, Ki = 0.34, Kd = 11; // PID constants
PID myPID(&Input, &Output, &Setpoint, Kp, Ki, Kd, DIRECT);

long lastEncoderPosition = 0;
long currentSliderValue = 0;
const int sliderMin = -5000;
const int sliderMax = 5000;
const int maxSpeed = 5000;
const int stepInterval = 25;
const int scaleFactor = 25;
const int encoderResolution = 1;

// Timing variables for Ticker
Ticker temperatureTicker;

// LPF parameters
const float alpha = 0.1; // Smoothing factor (adjust as needed)
float lastFilteredOutput = 0; // Last filtered PID output value

// Function to scale encoder value
long scaleEncoderValue(long value) {
  return value * scaleFactor;
}

// Function to round value to nearest multiple of scaleFactor
long roundToNearestScale(long value) {
  return (value / scaleFactor) * scaleFactor;
}

// Function to read temperature from thermistor
float readTemperature() {
    int analogValue = analogRead(A0); // Read analog value from A0
    if (analogValue == 0) {
        return 0.0; // Prevent division by zero
    }
    float resistance = R1 * (1023.0 / analogValue - 1); // Calculate resistance of thermistor
    float temperature = 1.0 / (log(resistance / R0) / BETA + 1.0 / T0) - 273.15; // Convert to temperature in Celsius
    return temperature;
}

// HTML content for the web page
const char htmlPage[] PROGMEM = R"rawliteral(
<!DOCTYPE html>
<html lang="en">
<head>
<meta charset="UTF-8">
<meta name="viewport" content="width=device-width, initial-scale=1.0">
<title>Encoder and Slider Sync</title>
<style>
  body {
    font-family: Arial, sans-serif;
    display: flex;
    flex-direction: column;
    align-items: center;
    justify-content: center;
    min-height: 100vh;
    margin: 0;
    background-color: #f4f4f9;
    text-align: center;
  }
  h1 {
    color: #333;
  }
  h2 {
    color: #555;
  }
  .container {
    width: 90%;
    max-width: 600px;
    padding: 20px;
    background: #fff;
    border-radius: 8px;
    box-shadow: 0 4px 8px rgba(0, 0, 0, 0.1);
  }
  .status {
    font-size: 20px;
    font-weight: bold;
  }
  input[type="range"] {
    margin: 10px 0;
  width: 80%;
  }
  
    input[type="number"] {
    margin: 10px 0;
  width: 10%;
  }
  
  
  
  button {
    padding: 10px 20px;
    font-size: 16px;
    border: none;
    border-radius: 5px;
    background-color: #007bff;
    color: #fff;
    cursor: pointer;
    margin: 10px;
  }
  button:hover {
    background-color: #0056b3;
  }
  p {
    margin: 10px 0;
  }
</style>
</head>
<body>
  <div class="container">
    
    <h2>Temperature Control</h2>
    <p>Current Temperature: <span id="temperatureValue">0</span> °C</p>
  <br>
  
  <p>Set Temperature:</p>
    <p> <input type="number" id="setTemp" value="100"> °C</p>
  
      <button id="setTempButton">Set Temperature</button>

    <h2>PID Control</h2>
    <p>Kp: <input type="number" id="kpValue" value="2" step="0.1"></p>
    <p>Ki: <input type="number" id="kiValue" value="5" step="0.1"></p>
    <p>Kd: <input type="number" id="kdValue" value="1" step="0.1"></p>
    <button id="applyPIDButton">Apply PID</button>
  </div>

  <script>
    var socket = new WebSocket('ws://' + location.hostname + '/ws');

    socket.onmessage = function(event) {
      var data = event.data;
      if (data.startsWith("TEMP:")) {
        document.getElementById('temperatureValue').innerText = data.substring(5);
      } else if (data.startsWith("SETPOINT:")) {
        document.getElementById('setTemp').value = data.substring(9);
      } else if (data.startsWith("PID:")) {
        var pidValues = data.substring(4).split(',');
        document.getElementById('kpValue').value = pidValues[0];
        document.getElementById('kiValue').value = pidValues[1];
        document.getElementById('kdValue').value = pidValues[2];
      } 
        
      
        
        //else if (data === "ENABLE") {
        //  document.getElementById('switchStatus').innerText = "Enabled";
       //   document.getElementById('switchStatus').style.color = "green";
      //  } 
        
                
        //else if (data === "DISABLE") {
       //   document.getElementById('switchStatus').innerText = "Disabled";
        //  document.getElementById('switchStatus').style.color = "red";
      //  }
      //}
    };


    //document.getElementById('resetButton').onclick = function() {
    //  socket.send('RESET');
   // };

    document.getElementById('setTempButton').onclick = function() {
      var setTemp = document.getElementById('setTemp').value;
      socket.send('SET_TEMP:' + setTemp);
    };

    document.getElementById('applyPIDButton').onclick = function() {
      var kp = document.getElementById('kpValue').value;
      var ki = document.getElementById('kiValue').value;
      var kd = document.getElementById('kdValue').value;
      socket.send('SET_PID:' + kp + ',' + ki + ',' + kd);
    };
  </script>
</body>
</html>


)rawliteral";

// Function to save parameters to SPIFFS
void saveParameters() {
  File file = SPIFFS.open("/params.csv", "w");
  if (!file) {
    Serial.println("Failed to open file for writing");
    return;
  }
  file.printf("%.2f,%.2f,%.2f,%.2f\n", Setpoint, Kp, Ki, Kd);
  file.close();
  Serial.println("Parameters saved");
}

// Function to load parameters from SPIFFS
void loadParameters() {
  File file = SPIFFS.open("/params.csv", "r");
  if (!file) {
    Serial.println("No saved parameters found");
    return;
  }

  String configData = file.readStringUntil('\n');
  file.close();

  int comma1 = configData.indexOf(',');
  int comma2 = configData.indexOf(',', comma1 + 1);
  int comma3 = configData.indexOf(',', comma2 + 1);

  Setpoint = configData.substring(0, comma1).toDouble();
  Kp = configData.substring(comma1 + 1, comma2).toDouble();
  Ki = configData.substring(comma2 + 1, comma3).toDouble();
  Kd = configData.substring(comma3 + 1).toDouble();

  myPID.SetTunings(Kp, Ki, Kd); // Apply loaded PID values
  Serial.println("Parameters loaded");
}

// Function to apply LPF
float applyLowPassFilter(float newValue) {
  lastFilteredOutput = alpha * newValue + (1 - alpha) * lastFilteredOutput;
  return lastFilteredOutput;
}

// Ticker callback for managing temperature
void temperatureCallback() {


  
  Input = readTemperature(); // Update input with the latest temperature reading

  // Check if temperature is valid (not NaN, zero, or abnormal)
  if (isnan(Input) || Input <= 0.0 || Input > 250.0) { // Assumes maximum valid temperature is 250°C
    analogWrite(MOSFET_PIN, 0); // Turn off MOSFET if temperature is invalid
    resetPosition(); // Reset stepper motor position
    Serial.println("Temperature not detected or abnormal! MOSFET off and stepper motor reset.");
    webSocket.textAll("ERROR: Temperature not detected or abnormal!");
    return; // Exit without running PID
  }
  
  myPID.Compute(); // Compute PID output

  // Apply LPF to PID output
  float smoothedOutput = applyLowPassFilter(Output);

  analogWrite(MOSFET_PIN, constrain(smoothedOutput, 0, 255)); // Apply PID output to MOSFET
  webSocket.textAll("TEMP:" + String(Input));
}


void setup() {
  Serial.begin(115200);

  if (!SPIFFS.begin()) {
    Serial.println("An error has occurred while mounting SPIFFS");
    return;
  }

  loadParameters(); // Load parameters from SPIFFS

  WiFi.mode(WIFI_AP);
  WiFi.softAP(apSSID, apPassword);
  IPAddress IP = WiFi.softAPIP();
  Serial.print("AP IP address: ");
  Serial.println(IP);

  webSocket.onEvent(onWebSocketEvent);
  server.addHandler(&webSocket);

  server.on("/", HTTP_GET, [](AsyncWebServerRequest *request){
    request->send_P(200, "text/html", htmlPage);
  });

  server.begin();

  stepper.setMaxSpeed(maxSpeed);
  stepper.setAcceleration(maxSpeed / 2);

  pinMode(BUTTON_PIN, INPUT_PULLUP);
  pinMode(ENABLE_PIN, OUTPUT);
  digitalWrite(ENABLE_PIN, LOW);

  pinMode(SWITCH_PIN, INPUT);
  pinMode(MOSFET_PIN, OUTPUT); 
  myPID.SetMode(AUTOMATIC); // Set PID mode to automatic

  // Initialize Ticker to call temperatureCallback every 2 seconds
  temperatureTicker.attach_ms(temperatureUpdateInterval, temperatureCallback);
}

void loop() {
  webSocket.cleanupClients();
  manageStepper();
}

void manageStepper() {
  bool switchState = digitalRead(SWITCH_PIN) == LOW;
  static bool lastSwitchState = HIGH;

  if (switchState != lastSwitchState) {
    lastSwitchState = switchState;
    if (switchState) {
      webSocket.textAll("ENABLE");
      digitalWrite(ENABLE_PIN, LOW);
    } else {
      webSocket.textAll("DISABLE");
      digitalWrite(ENABLE_PIN, HIGH);
    }
  }

  if (digitalRead(BUTTON_PIN) == LOW) {
    resetPosition();
    delay(200);
  }

  long rawEncoderPosition = encoder.read();
  long scaledEncoderPosition = scaleEncoderValue(rawEncoderPosition);
  scaledEncoderPosition = roundToNearestScale(scaledEncoderPosition);
  scaledEncoderPosition = constrain(scaledEncoderPosition, sliderMin, sliderMax);

  if (abs(scaledEncoderPosition - lastEncoderPosition) >= stepInterval) {
    lastEncoderPosition = scaledEncoderPosition;

    if (digitalRead(ENABLE_PIN) == LOW) {
      stepper.setSpeed(map(scaledEncoderPosition, sliderMin, sliderMax, -maxSpeed, maxSpeed));
    }
  }

  stepper.runSpeed();
}



void onWebSocketEvent(AsyncWebSocket *server, AsyncWebSocketClient *client, AwsEventType type, void *arg, uint8_t *payload, size_t length) 



{

  // Variable declaration moved outside of switch block
  String pidValues;

  switch(type) {
    case WS_EVT_DATA:
      if (strncmp((const char*)payload, "RESET", length) == 0) {
        resetPosition();
      } else if (strncmp((const char*)payload, "SET_TEMP:", 9) == 0) {
        Setpoint = atof((const char*)payload + 9); // Update set temperature
        saveParameters(); // Save parameter after update
        webSocket.textAll("SETPOINT:" + String(Setpoint));
      } else if (strncmp((const char*)payload, "SET_PID:", 8) == 0) {
        sscanf((const char*)payload + 8, "%lf,%lf,%lf", &Kp, &Ki, &Kd); // Update PID values
        myPID.SetTunings(Kp, Ki, Kd); // Apply new PID values
        saveParameters(); // Save parameters after update
        pidValues = String(Kp) + "," + String(Ki) + "," + String(Kd);
        webSocket.textAll("PID:" + pidValues);
      } else if (strncmp((const char*)payload, "ENABLE", length) == 0) {
        digitalWrite(ENABLE_PIN, LOW);
      } else if (strncmp((const char*)payload, "DISABLE", length) == 0) {
        digitalWrite(ENABLE_PIN, HIGH);
      } 
      break;

    case WS_EVT_CONNECT:
      Serial.println("Client connected");
      client->text("SETPOINT:" + String(Setpoint));
      pidValues = String(Kp) + "," + String(Ki) + "," + String(Kd);
      client->text("PID:" + pidValues);
      break;

    case WS_EVT_DISCONNECT:
      Serial.println("Client disconnected");
      break;

    case WS_EVT_ERROR:
      Serial.printf("WebSocket error %u\n", client->id());
      break;

    case WS_EVT_PONG:
      Serial.printf("WebSocket PONG received from client %u\n", client->id());
      break;
  }
}

void resetPosition() {
  encoder.write(0);
  stepper.setCurrentPosition(0);
  webSocket.textAll("0");
}
 

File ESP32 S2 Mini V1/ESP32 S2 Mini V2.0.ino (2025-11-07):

/**
*
// Some libraries used in this project may be licensed under different licenses. 
// Please refer to the LICENSE file for more information about those libraries.

 * ================================================
 * THIRD-PARTY LIBRARIES (MULTI-LICENSE)
 * ================================================
 * This project uses:

 * Third-party Libraries Attribution:
 * 

1. Wifi.h

    Description: 
    License: GNU Lesser General Public License (LGPL) v2.1 or later
    More Info: https://github.com/espressif/arduino-esp32/blob/master/libraries/WiFi/src/WiFi.h

2. ESPAsyncWebServer.h

    Description: 
    License: GNU Lesser General Public License (LGPL) v3.0 or later
    More Info: https://github.com/ESP32Async/ESPAsyncWebServer/blob/main/src/ESPAsyncWebServer.h

3. AsyncTCP.h

    Description: 
    License: GNU Lesser General Public License (LGPL) v3.0 or later
    More Info: https://github.com/ESP32Async/AsyncTCP/blob/main/src/AsyncTCP.h

4. PID_v1.h

    Description: Library for PID control algorithm.
    License: MIT License
    More Info:		https://github.com/br3ttb/Arduino-PID-Library
			http://brettbeauregard.com/blog/2011/04/improving-the-beginners-pid-introduction/

5. EEPROM.h

    Description: 
    License: GNU Lesser General Public License (LGPL) v2.1 or later
    More Info: https://github.com/espressif/arduino-esp32/blob/master/libraries/EEPROM/src/EEPROM.h

6. FastAccelStepper.h

    Description: 
    License: MIT License
    More Info: https://github.com/gin66/FastAccelStepper/blob/master/src/FastAccelStepper.h

7. Encoder.h

    Description: 
    License: MIT License
    More Info: https://www.pjrc.com/teensy/td_libs_Encoder.html

8. Adafruit_GFX.h>

    Description: 
    License: BSD License (2-clause BSD License)
    More Info: https://github.com/adafruit/Adafruit-GFX-Library/blob/master/Adafruit_GFX.h

9. Adafruit_SSD1306.h

    Description: 
    License: BSD License
    More Info: https://github.com/adafruit/Adafruit_SSD1306/blob/master/Adafruit_SSD1306.h
*
*
*
*/


#include <WiFi.h> 
#include <ESPAsyncWebServer.h> 
#include <AsyncTCP.h>
#include <PID_v1.h> 
#include <EEPROM.h> 
#include "FastAccelStepper.h" 
#include <Encoder.h> 
#include <Adafruit_GFX.h> 
#include <Adafruit_SSD1306.h>


/*
 * The code below is licensed under the MIT License.
 * 
 * MIT License
 * 
 * Copyright (c) 2025 13DCreator
 * 
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
 * THE SOFTWARE IS PROVIDED "AS IS", WITHOUT WARRANTY OF ANY KIND, EXPRESS OR
 * IMPLIED, INCLUDING BUT NOT LIMITED TO THE WARRANTIES OF MERCHANTABILITY,
 * FITNESS FOR A PARTICULAR PURPOSE, AND NONINFRINGEMENT. IN NO EVENT SHALL THE
 * AUTHORS OR COPYRIGHT HOLDERS BE LIABLE FOR ANY CLAIM, DAMAGES, OR OTHER
 * LIABILITY, WHETHER IN AN ACTION OF CONTRACT, TORT OR OTHERWISE, ARISING FROM,
 * OUT OF OR IN CONNECTION WITH THE SOFTWARE OR THE USE OR OTHER DEALINGS IN THE
 * SOFTWARE.
 */




// OLED Settings
#define SDA_PIN 35
#define SCL_PIN 37
#define SCREEN_WIDTH 128
#define SCREEN_HEIGHT 64
Adafruit_SSD1306 display(SCREEN_WIDTH, SCREEN_HEIGHT, &Wire, -1);

// Definisi pin untuk motor stepper
#define STEP_PIN 11
#define DIR_PIN 9
#define ENABLE_PIN 12

// Definisi pin untuk rotary encoder dan tombol
#define ENCODER_CLK 33
#define ENCODER_DT 18
#define BUTTON_PIN 16

// Definisi pin untuk switch
#define SWITCH_PIN 39

#define LED_PIN 15

FastAccelStepperEngine engine = FastAccelStepperEngine();
FastAccelStepper *stepper = NULL;

Encoder encoder(ENCODER_CLK, ENCODER_DT);

const float defaultEncoderScale = 5.0;
float encoderScale = defaultEncoderScale;

long lastEncoderPosition = 0;
long lastSpeed = 0;
const int maxSpeed = 10000;
const int acceleration = 3000;
const int SpeedInHz = 1000;

#define THERMISTOR_PIN 5
#define MOSFET_PIN 7

const float R1 = 950; //resistor
const float BETA = 3950;
const float T0 = 298.15;
const float R0 = 100000;

float currentTemperature = 0.0;
unsigned long lastUpdateTime = 0;
const unsigned long updateInterval = 2000; //Update Interval

double Setpoint = 60.0;
double Input, Output;
double Kp = 5, Ki = 0.8, Kd = 5;
PID myPID(&Input, &Output, &Setpoint, Kp, Ki, Kd, DIRECT);

AsyncWebServer server(80);

unsigned long motorTimerStart  = 0;       // Timer start time
unsigned long totalRunTime = 0;     // Total run time in milliseconds
bool motorRunning = false;          // Motor movement status

// Variabel untuk mendeteksi durasi tombol encoder
unsigned long buttonPressStartTime = 0;
bool buttonPressed = false;

//variabel pengaturan suhu
bool settingMode = false;      // Apakah dalam mode pengaturan
float tempSetpointDraft = 60;  // Draft setpoint suhu sementara


float readTemperature() {
  analogReadResolution(12);
  analogSetAttenuation(ADC_11db);

  int analogValue = analogRead(THERMISTOR_PIN);
  if (analogValue <= 0) {
    return -1.0;
  }

  float resistance = R1 * (4095.0 / analogValue - 1);
  float temperature = 1.0 / (log(resistance / R0) / BETA + 1.0 / T0) - 273.15;
  return temperature;
}

void saveSettings() {
  EEPROM.begin(512);
  EEPROM.put(0, Setpoint);
  EEPROM.put(sizeof(Setpoint), Kp);
  EEPROM.put(sizeof(Setpoint) + sizeof(Kp), Ki);
  EEPROM.put(sizeof(Setpoint) + sizeof(Kp) + sizeof(Ki), Kd);
  EEPROM.commit();
  EEPROM.end();
}

void loadSettings() {
  EEPROM.begin(512);
  EEPROM.get(0, Setpoint);
  EEPROM.get(sizeof(Setpoint), Kp);
  EEPROM.get(sizeof(Setpoint) + sizeof(Kp), Ki);
  EEPROM.get(sizeof(Setpoint) + sizeof(Kp) + sizeof(Ki), Kd);
  EEPROM.end();
}

void setup() {
  Serial.begin(115200);

  // Setup WiFi sebagai Access Point
  WiFi.softAP("13DC V2.0", "13dcreator");
  Serial.println("Access Point Created");
  Serial.print("IP Address: ");
  Serial.println(WiFi.softAPIP());

  // Muat pengaturan dari EEPROM saat boot
  loadSettings();

  // Setup untuk kontrol stepper
  engine.init();
  stepper = engine.stepperConnectToPin(STEP_PIN);
  if (stepper) {
    stepper->setDirectionPin(DIR_PIN);
    stepper->setEnablePin(ENABLE_PIN);
    stepper->setAutoEnable(true);
    stepper->setSpeedInHz(SpeedInHz);
    stepper->setAcceleration(acceleration);
    Serial.println("Stepper initialized");
  }

  pinMode(BUTTON_PIN, INPUT_PULLUP);
  pinMode(SWITCH_PIN, INPUT);
  pinMode(LED_PIN, OUTPUT);
  digitalWrite(LED_PIN, HIGH);

  // Setup OLED
  Wire.begin(SDA_PIN, SCL_PIN);
  if (!display.begin(SSD1306_SWITCHCAPVCC, 0x3C)) {
    Serial.println(F("OLED initialization failed"));
    while (true);
  }
  display.clearDisplay();
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

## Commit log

2025-11-07 Create ESP32 S2 Mini V2.0
2025-11-07 Update ESP32 S2 Mini V2.0
2025-11-07 Rename ESP32 S2 Mini V2.0 to ESP32 S2 Mini V2.0.ino
